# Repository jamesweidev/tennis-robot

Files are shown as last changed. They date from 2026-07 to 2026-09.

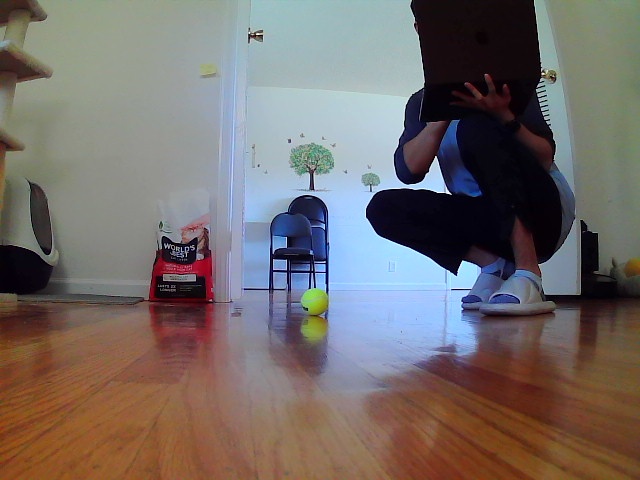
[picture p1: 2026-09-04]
projects/02_computer_vision/test_frames/test_frame.jpg

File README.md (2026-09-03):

# Tennis Robot Development

This repository documents my process of building the embedded, control, and vision subsystems for a tennis ball retrieving robot.

## Subsystems
Each subsystem will have its own project located in 'projects/', all of which will eventually be combined into an integrated prototype.
- Basic Automonous Mobile Base (using ultrasonic sensor)
- Vision-Based Tennis Ball Tracking
- Mobile Ball Finder
- Roller Ball Collector
- Integrated Prototype

## Current Focus

Currently working on a basic autonomous base using an ultrasonic sensor, cameras will be used later. 

## Firmware

All firmware uses HAL and are located in their respective project directory.

There are two ways to build the stm32 projects:
1. Use the STM32Cube vscode extension, or
2. Manually run the build commands below at any project root (such as [./projects/01_obstacle_avoiding_robot/firmware/STM32_ObjectAvoider](./projects/01_obstacle_avoiding_robot/firmware/STM32_ObjectAvoider))

Generate the build/Debug directory:
```shell
cmake -S . -B build/Debug -G Ninja -DCMAKE_BUILD_TYPE=Debug -DCMAKE_TOOLCHAIN_FILE=cmake/gcc-arm-none-eabi.cmake
```
Build the executables (this builds every executable created in its project):
```**shell**
cmake --build build/Debug
```

To flash the executables onto the board, first install [STM32CubeProgrammer](https://www.st.com/en/development-tools/stm32cubeprog.html#section-get-software-table) from STMicroelectronics if haven't already.

Then, either:
1. Use VSCode tasks, which are already setup in .vscode/ of each project directory (requires STM32CubeProgrammer to be in PATH), or
2. Manually run the following command:
   
```shell
/PATH/TO/STM32_Programmer_CLI -c port=SWD -w build/Debug/<NAME_OF_THE_ELF>.elf -v -rst
```
For example:
```shell
/Applications/STMicroelectronics/STM32Cube/STM32CubeProgrammer/STM32CubeProgrammer.app/Contents/Resources/bin/STM32_Programmer_CLI -c port=SWD -w build/Debug/V2_WithEncoders.elf -v -rst
```

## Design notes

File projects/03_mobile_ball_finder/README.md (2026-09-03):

# Mobile Ball Finder

This project combines project 1 and 2, and the goal is to have the robot find the tennis ball, then go towards it.

## Harware 

- STM32 Nucleo-F446RE
- Raspberry Pi 4
- HC-SR04 ultrasonic sensor
- 2 x DC Motor with encoder POLOLU-4865
- 2 x MPQ6612A motor driver
- 2200mAh LiPo battery
- USB2.0 1080P camera - innomaker U20CAM

## Wiring

| Component | MCU Pin | STM32 Function | Purpose |
|---|---|---|---|
| HC-SR04 TRIG | PA8 | GPIO Output | Ultrasonic trigger |
| HC-SR04 ECHO | PA9 | GPIO Input | Ultrasonic echo input |
| MPQ6612A AIN1 | PA0 | TIM2_CH1 PWM | Right motor PWM |
| MPQ6612A AIN2 | PA1 | TIM2_CH2 PWM | Right motor PWM |
| MPQ6612A BIN1 | PB10 | TIM2_CH3 PWM | Left motor PWM |
| MPQ6612A BIN2 | PB2 | TIM2_CH4 PWM | Left motor PWM |
| MPQ6612A GND | STM32 GND | Ground | Common ground |
| Left ENCB | PB4 | TIM3_CH1 IC | Left motor encoder B |
| Left ENCA | PB5 | TIM3_CH2 IC | Left motor encoder A |
| Right ENCA | PB6 | TIM4_CH1 IC | Right motor encoder A |
| Right ENCB | PB7 | TIM4_CH2 IC | Right motor encoder B |
| RPi Rx | PC6 | UART6 Rx | MCU to RPi UART Rx |
| RPi Tx | PC7 | UART6 Tx | MCU to RPi UART Tx |

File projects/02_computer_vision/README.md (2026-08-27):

# Computer Vision for Tennis Ball Detection

Computer vision script for detecting tennis balls and their relative location from the camera. Will be later integrated to the mobile base.

# Goals

 - Can consistently detect a tennis ball under various lightings and backgrounds
 - Outputs the distance and angle of the ball relative to the camera

 # Hardware
 - Raspberry Pi 4 with a couple of heat sinks
 - USB2.0 1080P camera - innomaker U20CAM

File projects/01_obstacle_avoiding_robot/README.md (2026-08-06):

# Autonomous Mobile Base

Basic STM32 based robot that drives around and avoids hitting objects. Used for learning the fundamentals, beyond which it serves no purpose whatsoever.

## Versions
| Version | Feature | Status |
|---|---|---|
| v1 | Obstacle Avoidance w/ HC-SR04 | Done |
| v2 | Relative Positioning w/ Encoders | Done |
| v3 | Collision Avoidance | Done |
---

## Demos
All demos are (not yet) in 'media/' 

## V1: Obstacle Avoidance

1. Drives forward
2. Measures distance using HC-SR04
3. Either turn or reverse when an object is too close

## Hardware

- STM32 Nucleo-F446RE
- HC-SR04 ultrasonic sensor
- L298N motor driver
- 4 DC motors
- Li-ion battery

## Wiring

| Component | MCU Pin | STM32 Function | Purpose |
|---|---|---|---|
| HC-SR04 TRIG | PA8 | GPIO Output | Ultrasonic trigger |
| HC-SR04 ECHO | PA9 | GPIO Input | Ultrasonic echo input |
| L298N IN1 | PA6 | GPIO Output | Right motor direction |
| L298N IN2 | PA7 | GPIO Output | Right motor direction |
| L298N IN3 | PA4 | GPIO Output | Left motor direction |
| L298N IN4 | PA5 | GPIO Output | Left motor direction |
| L298N ENA | PA0 | TIM4_CH1 PWM | Right motor speed |
| L298N ENB | PA1 | TIM3_CH1 PWM | Left motor speed |
| L298N GND | STM32 GND | Ground | Common ground |

## Firmware
Firmware is located at [firmware/STM32_ObjectAvoider/Core/V1_BasicAvoidance](firmware/STM32_ObjectAvoider/Core/V1_BasicAvoidance)

- GPIO for motor direction
- Timer/SysTick for delays
- Ultrasonic trigger/echo measurement
- Basic control logic in main loop

---

## V2: Relative Positioning w/ Encoder

1. Robot can go straight using encoder feedback loop.
2. Can move forward a specific distance by counting encoder ticks

## Hardware Changes From V1

- Wheeltec MG310 motor (With encoder)
- Use MPQ6612A instead of L298N motor driver
  - Better efficiency
  - MG310 motor stall consumes max 2A, but L298N is only rated for 2A continuous, while the MPQ6612A is rated 5A continuous
- Uses a smaller Li-Po battery rather than the massive li-ion that includes BMS
- Use a voltage monitor and alert set to 3.3V per cell
- Updated Chassis
  - Thicker walls since V1 was quite fragile
  - Added a power switch mount.
  - Wider and thicker mount for ultrasonic sensor (ultrasonic sensor is not used for v2)

## Wiring

| Component | MCU Pin | STM32 Function | Purpose |
|---|---|---|---|
| HC-SR04 TRIG | PA8 | GPIO Output | Ultrasonic trigger |
| HC-SR04 ECHO | PA9 | GPIO Input | Ultrasonic echo input |
| MPQ6612A AIN1 | PA0 | TIM2_CH1 PWM | Right motor PWM |
| MPQ6612A AIN2 | PA1 | TIM2_CH2 PWM | Right motor PWM |
| MPQ6612A BIN1 | PB10 | TIM2_CH3 PWM | Left motor PWM |
| MPQ6612A BIN2 | PB2 | TIM2_CH4 PWM | Left motor PWM |
| MPQ6612A GND | STM32 GND | Ground | Common ground |
| Right ENCA | PB6 | TIM4_CH1 IC | Right motor encoder A |
| Right ENCB | PB7 | GPIO Input | Right motor encoder B |
| Left ENCA | PB8 | TIM4_CH3 IC | Left motor encoder A |
| Left ENCB | PB9 | GPIO Input | Left motor encoder B |

## Firmware Changes From V1
This version is overwritten by V3, but it can be accessed at [firmware/STM32_ObjectAvoider/Core/V2_WithEncoders](firmware/STM32_ObjectAvoider/Core/V2_WithEncoders) in tag p1v2.

- Input capture for counting encoder ticks
- 100ms timer that updates PID values and subsequently the motor speeds
- Smooth_Drive function that briefly pauses in between direction switches to avoid jitters
- Offset_Position function that turns by x degrees and moves forward by y meters

---

## V3: Collision Avoidance

1. Everything that V2 does
2. Add back the obstacle avoidance from V1, which can override the position commands in order to avoid collisions

## Harware 

Same as V2

## Wiring

| Component | MCU Pin | STM32 Function | Purpose |
|---|---|---|---|
| HC-SR04 TRIG | PA8 | GPIO Output | Ultrasonic trigger |
| HC-SR04 ECHO | PA9 | GPIO Input | Ultrasonic echo input |
| MPQ6612A AIN1 | PA0 | TIM2_CH1 PWM | Right motor PWM |
| MPQ6612A AIN2 | PA1 | TIM2_CH2 PWM | Right motor PWM |
| MPQ6612A BIN1 | PB10 | TIM2_CH3 PWM | Left motor PWM |
| MPQ6612A BIN2 | PB2 | TIM2_CH4 PWM | Left motor PWM |
| MPQ6612A GND | STM32 GND | Ground | Common ground |
| Right ENCA | PB6 | TIM4_CH1 IC | Right motor encoder A |
| Right ENCB | PB7 | GPIO Input | Right motor encoder B |
| Left ENCA | PB8 | TIM4_CH3 IC | Left motor encoder A |
| Left ENCB | PB9 | GPIO Input | Left motor encoder B |
| RPi Rx | PC6 | UART6 Rx | MCU to RPi UART Rx |
| RPi Tx | PC7 | UART6 Tx | MCU to RPi UART Tx |

## Firmware Changes From V2

Firmware is located at [firmware/STM32_ObjectAvoider/Core/V3_CollisionAvoidance](firmware/STM32_ObjectAvoider/Core/V3_CollisionAvoidance).

- Refactor robot's blocking control logic to use non blocking state machine.
- Add an OBSTACLE_DETECTED state, which stops the robot in whatever it's doing, and reverses until the obstacle is far enough away.

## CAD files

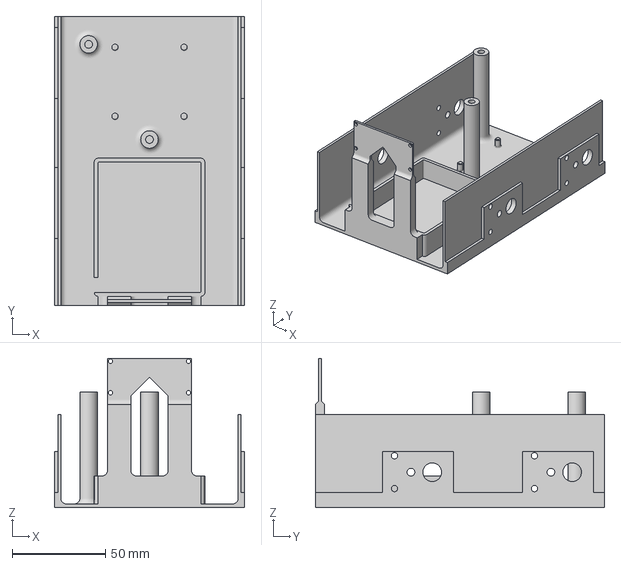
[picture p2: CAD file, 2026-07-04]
projects/01_obstacle_avoiding_robot/cad/print/V1_Chassis.3mf
101.8 x 155.0 x 80.0 mm

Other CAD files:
projects/01_obstacle_avoiding_robot/cad/step/V2_Chassis.step

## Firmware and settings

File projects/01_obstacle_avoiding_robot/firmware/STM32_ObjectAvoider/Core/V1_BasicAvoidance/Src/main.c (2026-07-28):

#include "main.h"
#include "stm32f4xx_hal.h"
#include "stm32f4xx_hal_def.h"
#include "stm32f4xx_hal_gpio.h"
#include "stm32f4xx_hal_rcc.h"
#include "stm32f4xx_hal_tim.h"
#include "stm32f4xx_hal_uart.h"
#include <stdio.h>
#include <string.h>


TIM_HandleTypeDef htim2 = {0};
TIM_HandleTypeDef htim3 = {0};
UART_HandleTypeDef huart1 = {0};

char msg[64];

int main(void)
{
	HAL_Init();
	SystemClock_Config();

	TIM3_Micros_Init();
	PWM_Init();
	Ultrasonic_GPIO_Init();

	UART1_Init();

	while (1)
	{
		uint32_t distance = get_distance();

		if (distance == 0)
		{
			for (uint8_t num_zeros = 0; num_zeros < 5; num_zeros++)
			{
				// Sensor randomly returns 0
				// If that happens just get the distance a couple more times
				distance = get_distance();
			}
		}


		// sprintf(msg, "distance is: %lu\r\n", distance);
		// if (HAL_UART_Transmit(&huart1, (uint8_t*) msg, strlen(msg), 0xFFFFFFFF) != HAL_OK)
		// {
		// 	Error_Handler();
		// }


		if (distance >= 500 || distance == 0)
		{
			// Sensor times out and returns 0 if It's too far from the closest object
			// So robot should go forward when distance == 0
			Perform_Action(65, ACTION_FORWARD);
		} else if (distance >= 150)
		{
			Perform_Action(65, ACTION_RIGHT);
		} else 
		{
			Perform_Action(75, ACTION_REVERSE);
			HAL_Delay(100);
		}

	}
	return 0;
}

void Perform_Action(uint32_t speed, ActionType type)
{
	motor_direction_config(type);

	speed = PWM_PERIOD * speed / 100;

	__HAL_TIM_SET_COMPARE(&htim2, TIM_CHANNEL_1, speed);
	__HAL_TIM_SET_COMPARE(&htim2, TIM_CHANNEL_2, speed);
}

void PWM_Init(void)
{
	TIM_OC_InitTypeDef pwm_init = {0};

	// Period of 20kHz
	htim2.Instance = TIM2;
	htim2.Init.Period = PWM_PERIOD - 1;
	htim2.Init.Prescaler = 1 - 1;

	pwm_init.Pulse = 0;
	pwm_init.OCMode = TIM_OCMODE_PWM1;
	pwm_init.OCPolarity = TIM_OCPOLARITY_HIGH;

	if (HAL_TIM_PWM_Init(&htim2) != HAL_OK)
	{
		Error_Handler();
	}

	// Channel 1 (Right PWM) config
	if (HAL_TIM_PWM_ConfigChannel(&htim2, &pwm_init, TIM_CHANNEL_1) != HAL_OK)
	{
		Error_Handler();
	}

	if (HAL_TIM_PWM_Start(&htim2, TIM_CHANNEL_1) != HAL_OK)
	{
		Error_Handler();
	}

	// Channel 2 (Left PWM) config
	if (HAL_TIM_PWM_ConfigChannel(&htim2, &pwm_init, TIM_CHANNEL_2) != HAL_OK)
	{
		Error_Handler();
	}

	if (HAL_TIM_PWM_Start(&htim2, TIM_CHANNEL_2) != HAL_OK)
	{
		Error_Handler();
	}
}

void Stop_Robot(void)
{
	Perform_Action(0, ACTION_STOP);
}

void Ultrasonic_GPIO_Init(void)
{
	__HAL_RCC_GPIOA_CLK_ENABLE();
	GPIO_InitTypeDef gpio_init = {0};

	gpio_init.Pull = GPIO_NOPULL;
	gpio_init.Speed = GPIO_SPEED_FREQ_LOW;
	
	// Configuring Trig
	gpio_init.Mode = GPIO_MODE_OUTPUT_PP;
	gpio_init.Pin = US_TRIG_PIN;
	HAL_GPIO_Init(US_GPIO_PORT, &gpio_init);

	// Configuring Echo
	gpio_init.Mode = GPIO_MODE_INPUT;
	gpio_init.Pin = US_ECHO_PIN;
	HAL_GPIO_Init(US_GPIO_PORT, &gpio_init);
}

void motor_direction_config(ActionType type)
{
	// Sets motor driver direction pins
	if (type == ACTION_FORWARD)
	{
		HAL_GPIO_WritePin(MOTOR_DRIVER_IN_PORT, IN1_PIN, GPIO_PIN_RESET);
		HAL_GPIO_WritePin(MOTOR_DRIVER_IN_PORT, IN2_PIN, GPIO_PIN_SET);
		HAL_GPIO_WritePin(MOTOR_DRIVER_IN_PORT, IN3_PIN, GPIO_PIN_RESET);
		HAL_GPIO_WritePin(MOTOR_DRIVER_IN_PORT, IN4_PIN, GPIO_PIN_SET);
	} else if (type == ACTION_REVERSE)
	{
		HAL_GPIO_WritePin(MOTOR_DRIVER_IN_PORT, IN1_PIN, GPIO_PIN_SET);
		HAL_GPIO_WritePin(MOTOR_DRIVER_IN_PORT, IN2_PIN, GPIO_PIN_RESET);
		HAL_GPIO_WritePin(MOTOR_DRIVER_IN_PORT, IN3_PIN, GPIO_PIN_SET);
		HAL_GPIO_WritePin(MOTOR_DRIVER_IN_PORT, IN4_PIN, GPIO_PIN_RESET);
	} else if (type == ACTION_LEFT)
	{
		HAL_GPIO_WritePin(MOTOR_DRIVER_IN_PORT, IN1_PIN, GPIO_PIN_RESET);
		HAL_GPIO_WritePin(MOTOR_DRIVER_IN_PORT, IN2_PIN, GPIO_PIN_SET);
		HAL_GPIO_WritePin(MOTOR_DRIVER_IN_PORT, IN3_PIN, GPIO_PIN_SET);
		HAL_GPIO_WritePin(MOTOR_DRIVER_IN_PORT, IN4_PIN, GPIO_PIN_RESET);
	} else if (type == ACTION_RIGHT)
	{
		HAL_GPIO_WritePin(MOTOR_DRIVER_IN_PORT, IN1_PIN, GPIO_PIN_SET);
		HAL_GPIO_WritePin(MOTOR_DRIVER_IN_PORT, IN2_PIN, GPIO_PIN_RESET);
		HAL_GPIO_WritePin(MOTOR_DRIVER_IN_PORT, IN3_PIN, GPIO_PIN_RESET);
		HAL_GPIO_WritePin(MOTOR_DRIVER_IN_PORT, IN4_PIN, GPIO_PIN_SET);
	} else if (type == ACTION_STOP)
	{
		HAL_GPIO_WritePin(MOTOR_DRIVER_IN_PORT, IN1_PIN, GPIO_PIN_RESET);
		HAL_GPIO_WritePin(MOTOR_DRIVER_IN_PORT, IN2_PIN, GPIO_PIN_RESET);
		HAL_GPIO_WritePin(MOTOR_DRIVER_IN_PORT, IN3_PIN, GPIO_PIN_RESET);
		HAL_GPIO_WritePin(MOTOR_DRIVER_IN_PORT, IN4_PIN, GPIO_PIN_RESET);
	}
}

uint32_t get_distance(void)
{
	// Sends initial pulse
	HAL_GPIO_WritePin(US_GPIO_PORT, US_TRIG_PIN, GPIO_PIN_SET);
	delay_us(10);
	HAL_GPIO_WritePin(US_GPIO_PORT, US_TRIG_PIN, GPIO_PIN_RESET);


	uint32_t timeout_start = micros();
	// Wait until pulse returns, then start counting. if timedout, return 0
	while (HAL_GPIO_ReadPin(US_GPIO_PORT, US_ECHO_PIN) != GPIO_PIN_SET)
	{
		if (micros() - timeout_start >= 38000)
		{
			return 0;
		}
	}

	uint32_t pulse_start = micros();
	// Wait until pulse ends, return the pulse length
	while (HAL_GPIO_ReadPin(US_GPIO_PORT, US_ECHO_PIN) == GPIO_PIN_SET)
	{
		if (micros() - pulse_start >= 38000)
		{
			return 0;
		}
	}

	uint32_t duration_us = micros() - pulse_start;

	// get the distance via time elapsed * speed of sound
	uint32_t distance = duration_us * 343 / 2000; // 0.343 mm/us


	return distance;
}

void TIM3_Micros_Init(void)
{
	htim3.Instance = TIM3;
	htim3.Init.Period = 0xFFFFFFFF;
	htim3.Init.Prescaler = 50 - 1; // 1 MHz clock, 1 µs per tick

	if (HAL_TIM_Base_Init(&htim3) != HAL_OK)
	{
		Error_Handler();
	}

	if (HAL_TIM_Base_Start(&htim3) != HAL_OK)
	{
		Error_Handler();
	}
}

uint32_t micros(void)
{
	return __HAL_TIM_GET_COUNTER(&htim3);
}

void delay_us(uint32_t us)
{
	uint32_t start_micros = micros();
	while (micros() - start_micros < us);
}

void SystemClock_Config(void)
{
    RCC_OscInitTypeDef osc_init = {0};
    RCC_PLLInitTypeDef pll_init = {0};

    osc_init.OscillatorType = RCC_OSCILLATORTYPE_HSE;
    osc_init.HSEState = RCC_HSE_BYPASS;

    pll_init.PLLState = RCC_PLL_ON;
    pll_init.PLLSource = RCC_PLLSOURCE_HSE;
    pll_init.PLLM = 8;
    pll_init.PLLN = 100;
    pll_init.PLLP = 2;
    pll_init.PLLR = 2;
    pll_init.PLLQ = 2;

    osc_init.PLL = pll_init;

    if (HAL_RCC_OscConfig(&osc_init) != HAL_OK)
    {
        Error_Handler();
    }

    RCC_ClkInitTypeDef clk_init = {0};
    clk_init.ClockType = RCC_CLOCKTYPE_HCLK | RCC_CLOCKTYPE_PCLK1 | RCC_CLOCKTYPE_PCLK2 | RCC_CLOCKTYPE_SYSCLK;
    clk_init.SYSCLKSource = RCC_SYSCLKSOURCE_PLLCLK;
    clk_init.AHBCLKDivider = RCC_SYSCLK_DIV1;
    clk_init.APB1CLKDivider = RCC_HCLK_DIV1;
    clk_init.APB2CLKDivider = RCC_HCLK_DIV2;

    if (HAL_RCC_ClockConfig(&clk_init, FLASH_LATENCY_1) != HAL_OK)
    {
        Error_Handler();
    }
}

void UART1_Init(void)
{
	huart1.Instance = USART1;
	huart1.Init.BaudRate = 115200;
	huart1.Init.Mode = UART_MODE_TX;
	huart1.Init.OverSampling = UART_OVERSAMPLING_16;
	huart1.Init.WordLength = UART_WORDLENGTH_8B;
	huart1.Init.Parity = UART_PARITY_NONE;
	huart1.Init.StopBits = UART_STOPBITS_1;

	if (HAL_UART_Init(&huart1) != HAL_OK)
	{
		Error_Handler();
	}
}

void Error_Handler(void)
{
	while (1);
}

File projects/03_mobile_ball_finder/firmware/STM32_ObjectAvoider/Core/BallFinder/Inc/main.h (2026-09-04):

#ifndef MAIN_H_
#define MAIN_H_

#include <stdio.h>
#include <string.h>
#include <stdint.h>
#include <stdlib.h>
#include <math.h>
#include "stm32f4xx_hal.h"

#define PWM_PERIOD                  2500

#define US_GPIO_PORT			    GPIOA
#define US_TRIG_PIN				    GPIO_PIN_8
#define US_ECHO_PIN 			    GPIO_PIN_9


// New motor driver pins
#define RIGHT_MOTOR_DRIVER_PORT     GPIOA
#define AIN1_PIN				    GPIO_PIN_0
#define AIN1_CHANNEL                TIM_CHANNEL_1
#define AIN2_PIN				    GPIO_PIN_1
#define AIN2_CHANNEL                TIM_CHANNEL_2

#define LEFT_MOTOR_DRIVER_PORT      GPIOB
#define BIN1_PIN				    GPIO_PIN_10
#define BIN1_CHANNEL                TIM_CHANNEL_3
#define BIN2_PIN				    GPIO_PIN_2
#define BIN2_CHANNEL                TIM_CHANNEL_4


// Encoder IC is on TIM4
#define RIGHT_ENCA_PORT             GPIOB
#define RIGHT_ENCA_PIN              GPIO_PIN_6

#define RIGHT_ENCB_PORT             GPIOB
#define RIGHT_ENCB_PIN              GPIO_PIN_7

#define LEFT_ENCA_PORT              GPIOB
#define LEFT_ENCA_PIN               GPIO_PIN_4

#define LEFT_ENCB_PORT              GPIOB
#define LEFT_ENCB_PIN               GPIO_PIN_5

// Drive constants
#define PRE_GEAR_TICKS              48
#define GEAR_RATIO                  46.85f

#define WHEEL_DIAM_M                0.08f
#define WHEEL_CIRCUMFERENCE         (WHEEL_DIAM_M * M_PI)
#define TICKS_PER_ROTATION          (PRE_GEAR_TICKS * GEAR_RATIO)
#define TICKS_PER_METER             (TICKS_PER_ROTATION / WHEEL_CIRCUMFERENCE)

#define WHEEL_DISTANCE_M            0.154f // Basically the diameter of the robot's rotation

// Command UART6
#define UART6_GPIO_PORT             GPIOC
#define UART6_TX_PIN                GPIO_PIN_6
#define UART6_RX_PIN                GPIO_PIN_7

// Debug UART3
#define USART3_TX_PORT              GPIOC
#define USART3_TX_PIN               GPIO_PIN_10

// Directions
typedef enum
{
    ACTION_FORWARD,
    ACTION_REVERSE,
    ACTION_LEFT,
    ACTION_RIGHT,
    ACTION_STOP
} ActionType;

typedef struct {
    float prev_err;
    float i_value;
} PID_State;

typedef struct {
	volatile uint16_t prev_ticks;
	volatile float current_rpm;
    volatile int32_t target_rpm;
    int32_t final_target_rpm; // used to for smoother motor speed setting
    int32_t ticks_elapsed; // Tick delta since the beginning of a movement
    float starting_rpm; // RPM at the beginning of a movement
    int32_t sync_correction;
    PID_State pid;
    uint32_t active_pwm_channel;
    uint32_t inactive_pwm_channel;

    uint32_t prev_millis;
    float s_elapsed;

    TIM_HandleTypeDef* htimx;
} Encoder;

typedef enum {
    STATE_IDLE,
    TURNING_TO_BALL,
    DRIVING_TO_BALL,
    OBSTACLE_DETECTED
} RobotState;

// Robot movement
void Smooth_Drive(ActionType new_action);
void Draw_Circle(float radius);
void Stop_Robot();
uint16_t Get_Ticks(Encoder* enc);

float Get_PID_Correction(Encoder* enc);

uint32_t Get_Turn_Ticks(float degs);

// Command Receive
void Receive_Command(void);
void Command_UART6_Init(void);
void Command_Receive_Callback(void);

// State
void Update_State(void);

// ultrasonic
float Get_Distance(void);
uint32_t micros(void);
void delay_us(uint32_t micros);

// Inits
void Ultrasonic_GPIO_Init(void);
void TIM6_Micros_Init(void);
void TIM2_PWM_Init(void);
void Encoder_TIM3_TIM4_Init(void);
void SystemClock_Config(void);
void PID_TIM7_Init(void);

// debugging
void Debug_UART2_Init(void);
void Error_Handler(void);
void Update_LED(void);

#endif

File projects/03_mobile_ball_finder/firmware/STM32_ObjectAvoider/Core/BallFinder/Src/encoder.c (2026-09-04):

#include "main.h"
#include "stm32f4xx_hal.h"
#include "stm32f4xx_hal_def.h"
#include "stm32f4xx_hal_tim.h"
#include <stdio.h>

extern TIM_HandleTypeDef htim2;

TIM_HandleTypeDef htim3 = {0};
TIM_HandleTypeDef htim4 = {0};
TIM_HandleTypeDef htim7 = {0};

Encoder right_encoder = {0};
Encoder left_encoder = {0};

static void Update_Encoder(Encoder* enc);
static uint32_t Get_Compare(Encoder* enc);
static void Set_Sync_Correction();

void Encoder_TIM3_TIM4_Init(void)
{
	TIM_Encoder_InitTypeDef encoder_init = {0};
	encoder_init.EncoderMode = TIM_ENCODERMODE_TI12;
	encoder_init.IC1Selection = TIM_ICSELECTION_DIRECTTI;
	encoder_init.IC2Selection = TIM_ICSELECTION_DIRECTTI;
	encoder_init.IC1Filter = 2;
	encoder_init.IC2Filter = 2;

	// Left encoder
    htim3.Instance = TIM3;
    htim3.Init.Period = 0xFFFF;
	htim3.Init.Prescaler = 0;
	left_encoder.htimx = &htim3;

    if (HAL_TIM_Encoder_Init(&htim3, &encoder_init) != HAL_OK)
	{
		Error_Handler();
	}

	if (HAL_TIM_Encoder_Start(&htim3, TIM_CHANNEL_ALL)) 
	{
		Error_Handler();
	}
	
	// Right encoder
    htim4.Instance = TIM4;
    htim4.Init.Period = 0xFFFF;
	htim4.Init.Prescaler = 0;
	right_encoder.htimx = &htim4;

    if (HAL_TIM_Encoder_Init(&htim4, &encoder_init) != HAL_OK)
	{
		Error_Handler();
	}

	if (HAL_TIM_Encoder_Start(&htim4, TIM_CHANNEL_ALL)) 
	{
		Error_Handler();
	}
}

void PID_TIM7_Init(void)
{
	htim7.Instance = TIM7;

	// 100 ms period
	htim7.Init.Period = 62500 - 1;
	htim7.Init.Prescaler = 80 - 1;

	if (HAL_TIM_Base_Init(&htim7) != HAL_OK)
	{
		Error_Handler();
	}

	if (HAL_TIM_Base_Start_IT(&htim7) != HAL_OK)
	{
		Error_Handler();
	}

}

/**
 * @brief Periodically update motor speed based on PID feedback. Runs every 100ms
 * 
 * @param htim 
 */
void HAL_TIM_PeriodElapsedCallback(TIM_HandleTypeDef *htim)
{
	// Update ticks and rpm
	Update_Encoder(&right_encoder);
	Update_Encoder(&left_encoder);
	
	// Avoid setting PWM in the case of a stopped robot
	// Stop_Robot() already set all channels to 0
	if (right_encoder.final_target_rpm == 0)
	{
		return;
	}

	// Set sync correction to correct for two motors running at slightly different rpm
	Set_Sync_Correction();


	printf("{\"r_rpm\": %.2f, \"r_ctarget\": %ld, \"r_ftarget\": %ld, \"r_starting\": %.2f, \"r_tick_elapsed\": %i,\"l_rpm\": %.2f, \"l_ctarget\": %ld, \"l_ftarget\": %ld, \"l_starting\": %.2f, \"l_tick_elapsed\": %i}\r\n", 
		right_encoder.current_rpm,
		right_encoder.target_rpm,
		right_encoder.final_target_rpm,
		right_encoder.starting_rpm,
		abs(right_encoder.ticks_elapsed),
		left_encoder.current_rpm,
		left_encoder.target_rpm,
		left_encoder.final_target_rpm,
		left_encoder.starting_rpm,
		abs(left_encoder.ticks_elapsed)
	);


	__HAL_TIM_SET_COMPARE(&htim2, right_encoder.active_pwm_channel, Get_Compare(&right_encoder));
	__HAL_TIM_SET_COMPARE(&htim2, left_encoder.active_pwm_channel, Get_Compare(&left_encoder));

	// Set the inactive channels to 0 so previous values wont carry over
	__HAL_TIM_SET_COMPARE(&htim2, right_encoder.inactive_pwm_channel, 0);
	__HAL_TIM_SET_COMPARE(&htim2, left_encoder.inactive_pwm_channel, 0);
}

uint16_t Get_Ticks(Encoder* enc)
{
	return (uint16_t)__HAL_TIM_GET_COUNTER(enc->htimx);
}

static uint32_t Get_Compare(Encoder* enc)
{
	float correction = Get_PID_Correction(enc);
	float BASE_DUTY = 0.1f;

	// Duty for motors to start moving
	float duty = correction + BASE_DUTY;

	if (enc->target_rpm < 0)
	{
		duty = BASE_DUTY - correction;
	}

	// cap duty to the limit values
	if (duty > 1) duty = 1;
	if (duty < 0) duty = 0;

	int32_t compare = (int32_t) (PWM_PERIOD * duty);

	return (uint32_t) compare;
}


static void Update_Encoder(Encoder* enc)
{	
	uint32_t cur_millis = HAL_GetTick();
	enc->s_elapsed = (cur_millis - enc->prev_millis) / 1000.0f;
	enc->prev_millis = cur_millis;

	uint16_t ticks = Get_Ticks(enc);
	int16_t tick_delta = (int16_t) (ticks - enc->prev_ticks);
	enc->ticks_elapsed += tick_delta;
	int16_t tick_rate = tick_delta / enc->s_elapsed;
	enc->prev_ticks = ticks;
	enc->current_rpm = (tick_rate * 60) / TICKS_PER_ROTATION;
}

static int32_t Get_Ticks_Diff()
{
	int32_t r_ticks = abs(right_encoder.ticks_elapsed);
	int32_t l_ticks = abs(left_encoder.ticks_elapsed);

	printf("ticks right: %li left: %li\r\n", r_ticks, l_ticks);

	return (int32_t) (r_ticks - (l_ticks * 0.99f));
}

static void Set_Sync_Correction()
{
	int32_t diff = Get_Ticks_Diff();

	int32_t correction = diff * 0.2f;

	int32_t r_final = right_encoder.final_target_rpm;
	int32_t l_final = left_encoder.final_target_rpm;

	right_encoder.target_rpm = r_final + correction * ((r_final < 0) ? 1 : -1);
	left_encoder.target_rpm = l_final + correction * ((l_final < 0) ? -1 : 1);
}

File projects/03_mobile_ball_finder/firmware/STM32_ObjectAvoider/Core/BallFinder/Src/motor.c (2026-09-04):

#include "main.h"
#include "stm32f4xx_hal.h"

TIM_HandleTypeDef htim2 = {0};

extern Encoder right_encoder;
extern Encoder left_encoder;

static void Drive_Motor(int32_t r_rpm, int32_t l_rpm, ActionType type);
static void motor_direction_config(ActionType type);

ActionType current_action = ACTION_STOP;

/**
 * @brief Returns the number of motor ticks it would take to rotate degs degrees
 * 
 * @param degs 
 */
uint32_t Get_Turn_Ticks(float degs)
{
	// Distance both wheels each have to travel to achieve a 180 deg rotation
	// which is just half the circumference
	float distance_180_deg = WHEEL_DISTANCE_M * 3.14f / 2;

	// The distance both wheels actually have to travel in meters
	// degs could be negative, but direction is already taken care of in state machine
	float m_to_travel = fabsf(distance_180_deg * degs / 180);

	// in ticks
	uint32_t rotate_ticks = (uint32_t) (m_to_travel * TICKS_PER_METER);

	// correction
	rotate_ticks *= 0.98f;

	return rotate_ticks;
}


void Draw_Circle(float radius)
{
	float wheel_to_wheel_m = 0.14;
	uint32_t high_rpm = 400;
	uint32_t low_rpm = high_rpm * (1 - wheel_to_wheel_m / radius);

	Drive_Motor(high_rpm, low_rpm, ACTION_FORWARD);
}

void Smooth_Drive(ActionType new_action)
{
	#define RPM 100

	if (current_action == ACTION_STOP)
	{
		Drive_Motor(RPM, RPM, new_action);
		current_action = new_action;
		return;
	}

	if (current_action != new_action)
	{
		// If the new action differs from current action
		// Stop the robot for some time first to prevent jitters
		Stop_Robot();
		HAL_Delay(1000);
		Drive_Motor(RPM, RPM, new_action);
		current_action = new_action;
	}
}

static void Drive_Motor(int32_t r_rpm, int32_t l_rpm, ActionType type)
{
	right_encoder.starting_rpm = right_encoder.current_rpm;
	left_encoder.starting_rpm = left_encoder.current_rpm;

	right_encoder.ticks_elapsed = 0;
	left_encoder.ticks_elapsed = 0;

    right_encoder.prev_millis = HAL_GetTick();
    left_encoder.prev_millis = HAL_GetTick();

	// Adjust the sign of rpm based on the specified direction
	if (type == ACTION_RIGHT || type == ACTION_REVERSE)
	{
		r_rpm *= -1;
	}
	if (type == ACTION_LEFT || type == ACTION_REVERSE)
	{
		l_rpm *= -1;
	}

	// reset i value if new rpm differs from previous. 
	if (right_encoder.final_target_rpm != r_rpm)
	{
		// Reset the PID i Value so it doesn't bleed into the next rpm
		right_encoder.pid.i_value = 0;
	}
	// Same for the left motor
	if (left_encoder.final_target_rpm != l_rpm)
	{
		left_encoder.pid.i_value = 0;
	}

	// Set the final RPM target
	right_encoder.final_target_rpm = r_rpm;
	left_encoder.final_target_rpm = l_rpm;

	// Initialize the target to the current rpm
	right_encoder.target_rpm = r_rpm;
	left_encoder.target_rpm = l_rpm;

	motor_direction_config(type);
}

void Stop_Robot()
{
	// Set to 0 for 0 speed
	__HAL_TIM_SET_COMPARE(&htim2, AIN1_CHANNEL, PWM_PERIOD);
	__HAL_TIM_SET_COMPARE(&htim2, AIN2_CHANNEL, PWM_PERIOD);
	__HAL_TIM_SET_COMPARE(&htim2, BIN1_CHANNEL, PWM_PERIOD);
	__HAL_TIM_SET_COMPARE(&htim2, BIN2_CHANNEL, PWM_PERIOD);

	// Rest all encoder values so they don't bleed into future speed settings
	right_encoder = (Encoder) {
		.htimx = right_encoder.htimx, 
		.prev_ticks = Get_Ticks(&right_encoder)
	};
	left_encoder = (Encoder) {
		.htimx = left_encoder.htimx, 
		.prev_ticks = Get_Ticks(&left_encoder)
	};

	current_action = ACTION_STOP;
}

void TIM2_PWM_Init(void)
{
	TIM_OC_InitTypeDef pwm_init = {0};

	// 20kHz Frequency
	htim2.Instance = TIM2;
	htim2.Init.Period = PWM_PERIOD - 1;
	htim2.Init.Prescaler = 1 - 1;

	pwm_init.Pulse = 0;
	pwm_init.OCMode = TIM_OCMODE_PWM1;
	pwm_init.OCPolarity = TIM_OCPOLARITY_HIGH;

	if (HAL_TIM_PWM_Init(&htim2) != HAL_OK)
	{
		Error_Handler();
	}

	// Right PWM config
	// AIN1
	if (HAL_TIM_PWM_ConfigChannel(&htim2, &pwm_init, AIN1_CHANNEL) != HAL_OK)
	{
		Error_Handler();
	}
	if (HAL_TIM_PWM_Start(&htim2, AIN1_CHANNEL) != HAL_OK)
	{
		Error_Handler();
	}
	// AIN2
	if (HAL_TIM_PWM_ConfigChannel(&htim2, &pwm_init, AIN2_CHANNEL) != HAL_OK)
	{
		Error_Handler();
	}
	if (HAL_TIM_PWM_Start(&htim2, AIN2_CHANNEL) != HAL_OK)
	{
		Error_Handler();
	}

	__HAL_TIM_SET_COMPARE(&htim2, AIN1_CHANNEL, 0);
	__HAL_TIM_SET_COMPARE(&htim2, AIN2_CHANNEL, 0);

	// Left PWM config
	// BIN1
	if (HAL_TIM_PWM_ConfigChannel(&htim2, &pwm_init, BIN1_CHANNEL) != HAL_OK)
	{
		Error_Handler();
	}
	if (HAL_TIM_PWM_Start(&htim2, BIN1_CHANNEL) != HAL_OK)
	{
		Error_Handler();
	}
	// BIN2
	if (HAL_TIM_PWM_ConfigChannel(&htim2, &pwm_init, BIN2_CHANNEL) != HAL_OK)
	{
		Error_Handler();
	}
	if (HAL_TIM_PWM_Start(&htim2, BIN2_CHANNEL) != HAL_OK)
	{
		Error_Handler();
	}
}

static void motor_direction_config(ActionType type)
{
	// Sets motor driver direction pins
	if (type == ACTION_FORWARD)
	{
		right_encoder.active_pwm_channel = AIN1_CHANNEL;
		left_encoder.active_pwm_channel = BIN1_CHANNEL;

		right_encoder.inactive_pwm_channel = AIN2_CHANNEL;
		left_encoder.inactive_pwm_channel = BIN2_CHANNEL;
	} else if (type == ACTION_REVERSE)
	{
		right_encoder.active_pwm_channel = AIN2_CHANNEL;
		left_encoder.active_pwm_channel = BIN2_CHANNEL;

		right_encoder.inactive_pwm_channel = AIN1_CHANNEL;
		left_encoder.inactive_pwm_channel = BIN1_CHANNEL;
	} else if (type == ACTION_LEFT)
	{
		right_encoder.active_pwm_channel = AIN1_CHANNEL;
		left_encoder.active_pwm_channel = BIN2_CHANNEL;

		right_encoder.inactive_pwm_channel = AIN2_CHANNEL;
		left_encoder.inactive_pwm_channel = BIN1_CHANNEL;
	} else if (type == ACTION_RIGHT)
	{
		right_encoder.active_pwm_channel = AIN2_CHANNEL;
		left_encoder.active_pwm_channel = BIN1_CHANNEL;

		right_encoder.inactive_pwm_channel = AIN1_CHANNEL;
		left_encoder.inactive_pwm_channel = BIN2_CHANNEL;
	}
}

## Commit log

2026-07-03 Update project structure, move ObjectAvoidingRobot to HAL
    went with HAL for the entire project. made changes to object avoiding robot's decision making, slightly decreased the chances of getting stuck at one place.
    [ObjectAvoider.ioc, main.c, main.h]
2026-07-04 add chassis 3mf
    [V1_Chassis.3mf]
2026-07-08 add step and print files for chassis
    [V1_Chassis.3mf, V2_Chassis.step]
2026-07-11 update V2 CAD files
    [V2_Chassis.step]
2026-07-13 prep for IMU testing
    added IMUTesting dir and build instructions to CMake
2026-07-18 enable I2C in stm32f4xx_ hal_conf.h
2026-07-18 Create IMUTesting dir and build
2026-07-18 chnage motor controls according to MPQ6612A
2026-07-18 add debug script that looks at a single frame
2026-07-18 improve debugging and ball detection calibration
2026-07-19 Send distance and angle over UART
2026-07-19 update README to reflect MPQ6612A motor driver wiring
2026-07-28 put ultrasonic filtering into get_distance()
2026-08-06 add V3 wiring and command UART pins
2026-08-16 refactor ball finder to use timer encoder mode rather than IC, and to work on the new pololu 25D motors
2026-09-03 Update README with VSCode tasks requirement
    Clarified instructions for using VSCode tasks with STM32CubeProgrammer.
2026-09-03 Smoothen motor movements + correct motor direction pins
    [command_receiver.c, encoder.c, main.c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]
2026-09-04 Fix motors having mismatched speeds
    [command_receiver.c, encoder.c, main.h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]
2026-09-04 fix wheel slip and random sudden movements
    the operating speed is decreased from 140 rpm to 100 rpm to prevent the wheels from slipping. fixed bug where prev_millis is reset to 0 after each motion, causing huge integral component values
    [ball_detection.py, contour_processing.py, debug.py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]
